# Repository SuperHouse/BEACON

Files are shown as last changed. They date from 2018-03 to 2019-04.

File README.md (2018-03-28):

IR / RF Transmitter / Receiver Beacon with WiFi
===============================================
Copyright 2016 SuperHouse Automation Pty Ltd  www.superhouse.tv  

Transmitter and receiver for both IR (infra-red) and 433MHz RF signals.
Includes a footprint for a Spark Core or Particle Photon.

Features:

 * Particle Photon controller
 * 433MHz transmitter
 * 433MHz receiver
 * I/R transmitter
 * I/R receiver
 * Status LEDs

More information:

  http://www.superhouse.tv/beacon

INSTALLATION
------------
The design is saved as an EAGLE project. EAGLE PCB design software is
available from www.cadsoftusa.com free for non-commercial use. To use
this project download it and place the directory containing these files
into the "eagle" directory on your computer. Then open EAGLE and
navigate to the project.

CREDITS
-------
Designed by Jonathan Oxer jon@oxer.com.au

DISTRIBUTION
------------
The specific terms of distribution of this project are governed by the
license referenced below.

LICENSE
-------
Licensed under the TAPR Open Hardware License (www.tapr.org/OHL).
The "license" folder within this repository also contains a copy of
this license in plain text format.

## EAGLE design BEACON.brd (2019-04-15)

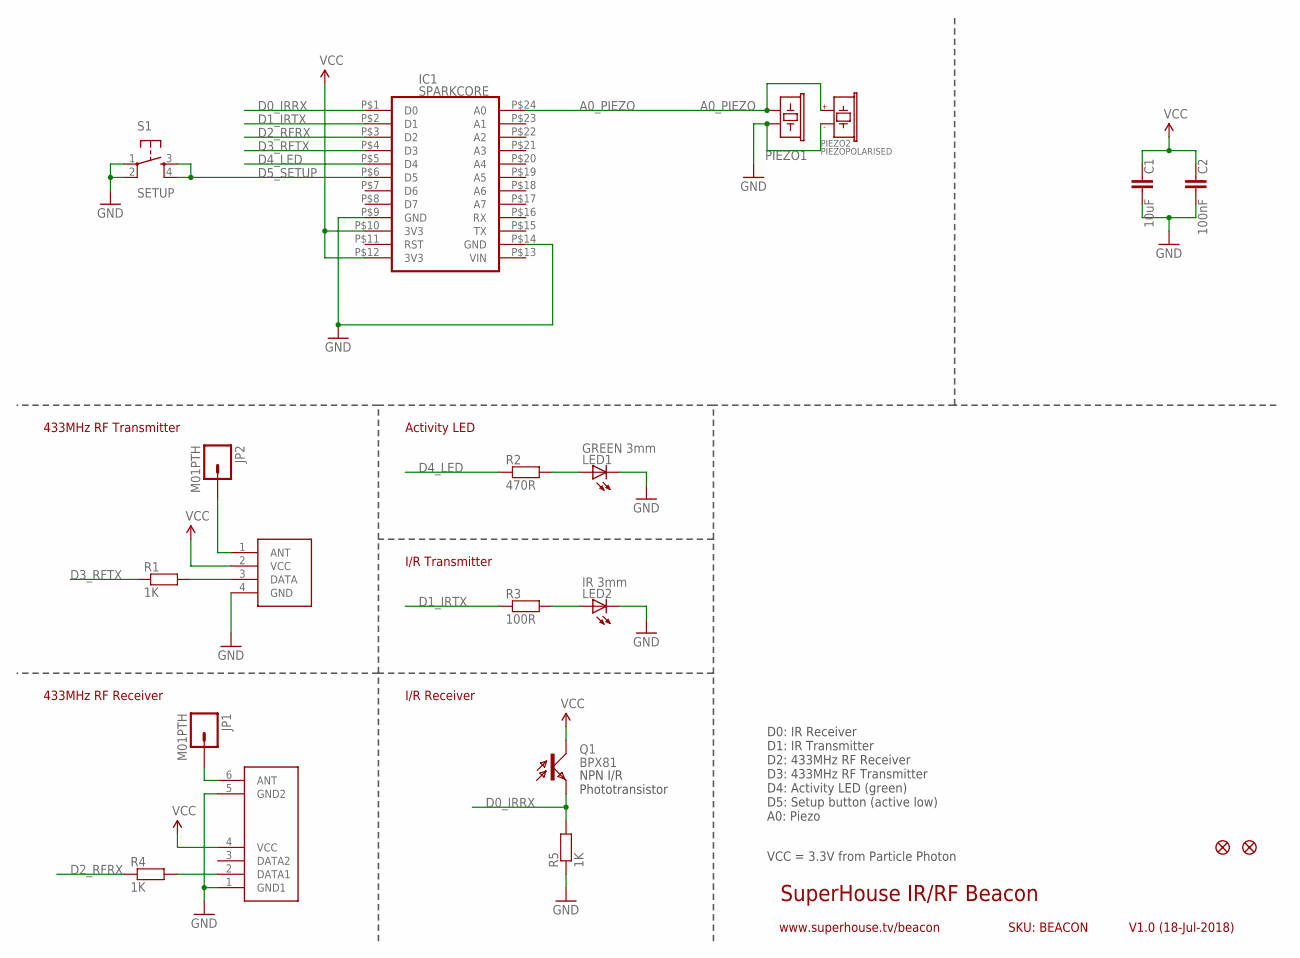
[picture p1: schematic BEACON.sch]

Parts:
C1: 10uF; C0805
C2: 100nF; 0603
IC1: SPARKCORE
IC2: TX-C1FLAT; TX-C1-FLAT
IC3: RXB1SHORTFLAT; RX-B1-SHORT-FLAT
JP1, JP2: M01PTH; 1X01
LED1: GREEN 3mm; LED3MM
LED2: IR 3mm; LED3MM
PIEZO1: BUZZERSMD12X12; BUZZER-12X12-SMT
PIEZO2: PIEZOPOLARISED; PIEZO12MMWIDEPOLARISED
Q1: BPX81
R1, R4, R5: 1K; 0603
R2: 470R; 0603
R3: 100R; 0603
S1: SETUP; TACTILE-PTH
U$4, U$5: FIDUCIAL1X2.5; FIDUCIAL-1X2.5

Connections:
A0_PIEZO: IC1.P$24 (A0), PIEZO1.1, PIEZO2.1 (+)
D0_IRRX: IC1.P$1 (D0), Q1.E, R5.2
D1_IRTX: IC1.P$2 (D1), R3.1
D2_RFRX: IC1.P$3 (D2), R4.1
D3_RFTX: IC1.P$4 (D3), R1.1
D4_LED: IC1.P$5 (D4), R2.1
D5_SETUP: IC1.P$6 (D5), S1.3, S1.4
GND: C1.1, C2.2, IC1.P$9 (GND), IC1.P$14 (GND), IC2.4 (GND), IC3.1 (GND1), IC3.5 (GND2), LED1.K (C), LED2.K (C), PIEZO1.2, PIEZO2.2 (-), R5.1, S1.1, S1.2
unnamed: LED1.A, R2.2
unnamed: IC2.3 (DATA), R1.2
unnamed: LED2.A, R3.2
unnamed: IC2.1 (ANT), JP2.1
unnamed: IC3.6 (ANT), JP1.1
unnamed: IC3.2 (DATA1), R4.2
VCC: C1.2, C2.1, IC1.P$10 (3V3), IC1.P$12 (3V3), IC2.2 (VCC), IC3.4 (VCC), Q1.C

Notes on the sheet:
SuperHouse IR/RF Beacon
SKU: BEACON
V1.0 (18-Jul-2018)
www.superhouse.tv/beacon
D0: IR Receiver D1: IR Transmitter D2: 433MHz RF Receiver D3: 433MHz RF Transmitter D4: Activity LED (green) D5: Setup button (active low) A0: Piezo
433MHz RF Transmitter
433MHz RF Receiver
Activity LED
I/R Receiver
I/R Transmitter
VCC = 3.3V from Particle Photon
NPN I/R Phototransistor

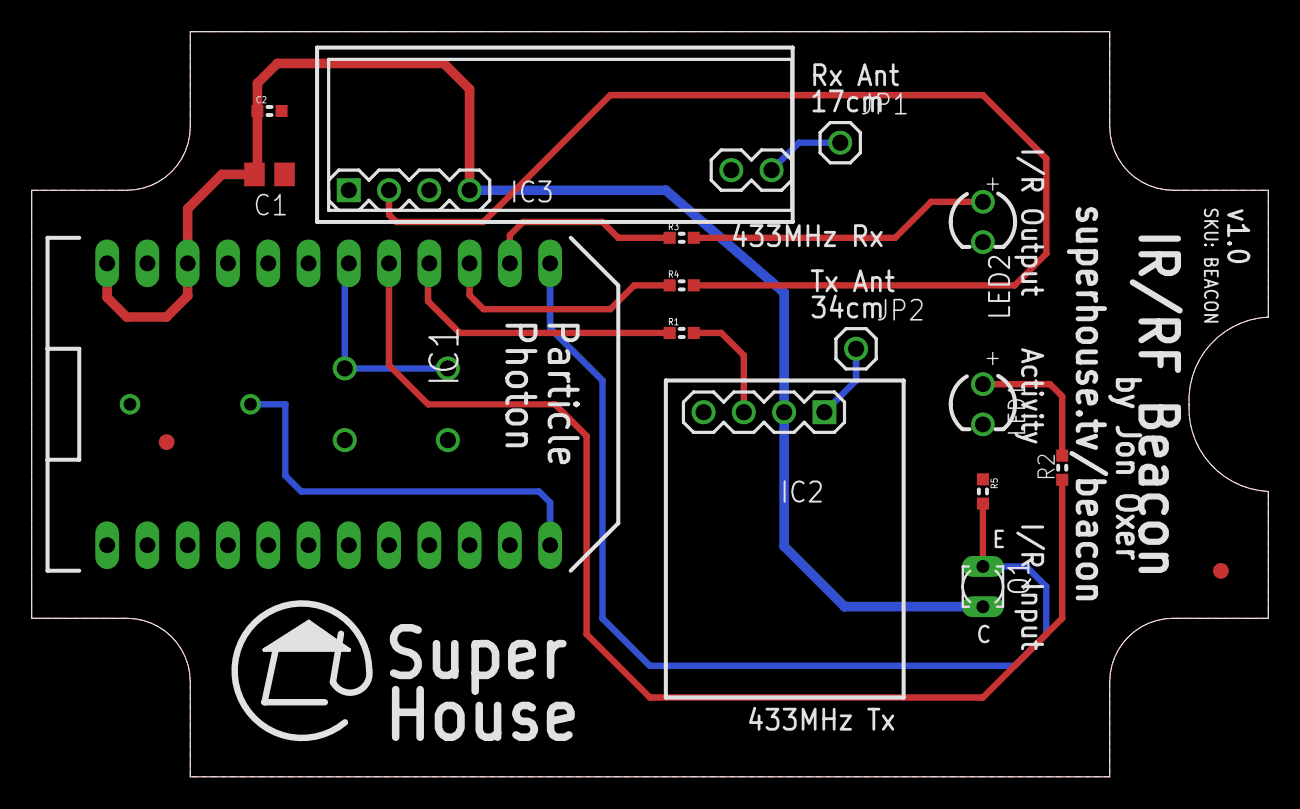
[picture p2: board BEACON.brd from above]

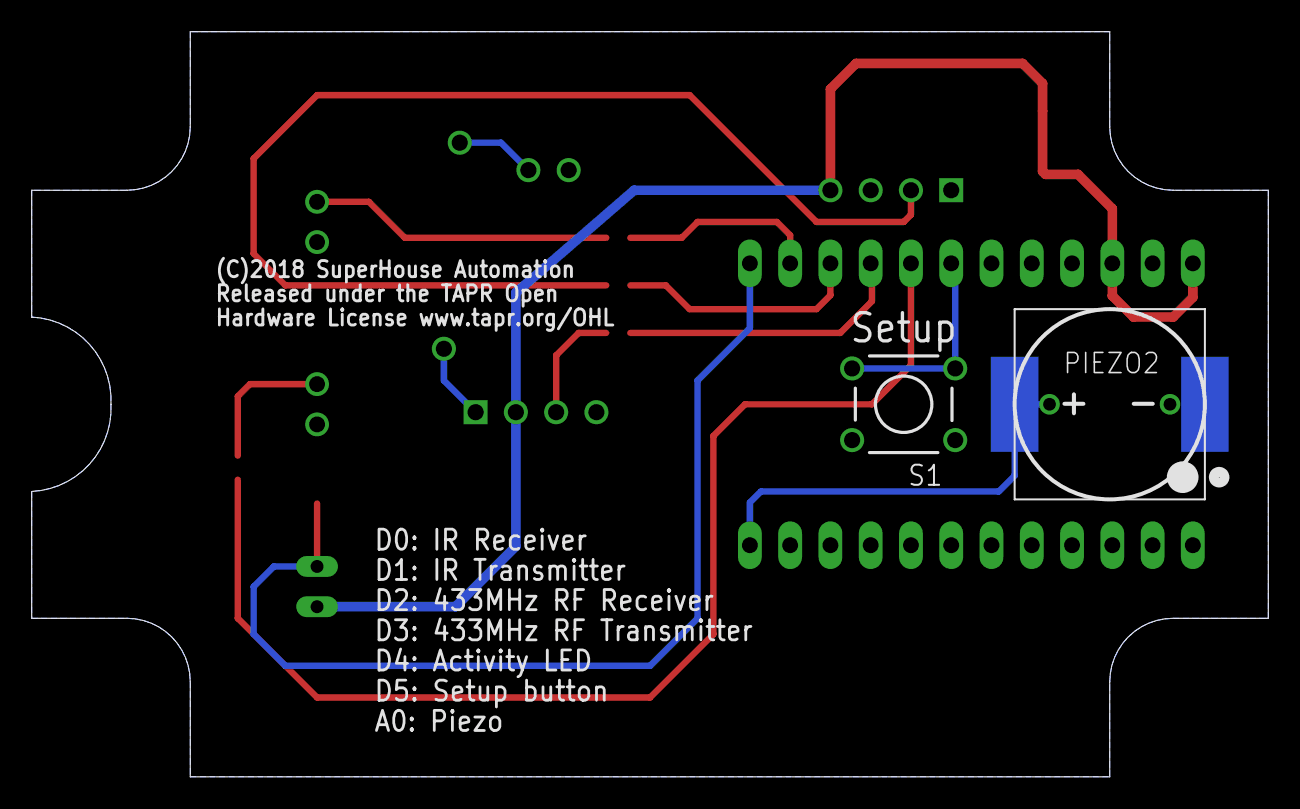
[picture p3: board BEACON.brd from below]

Board: 2 copper layers, 78.0 x 47.0 mm, 20 parts (3 on the bottom side), 15 nets.

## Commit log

2018-03-28 Initial import of project from Feb 2016
    [BEACON.brd, BEACON.sch]
2018-07-17 Reduced PCB outline and added action button to initiate binding
    [BEACON.brd, BEACON.sch]
2019-04-15 Added mechanical details
    [BEACON.brd, BEACON.sch]

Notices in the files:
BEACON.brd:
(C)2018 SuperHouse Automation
